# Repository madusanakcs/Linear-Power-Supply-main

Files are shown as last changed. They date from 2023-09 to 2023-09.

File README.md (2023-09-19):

# 10V Linear Power Supply

## Abstract

The objective of this project was to design a 10V Linear power supply with a maximum current rating of 10A. This report presents the design of a voltage regulator from scratch to drive a high-power load (100W) from a 230V input voltage.

## Introduction

Power supplies are used to drive various loads under constant voltage/current conditions. To ensure the reliable operation of a power supply several factors need to be considered including load regulation, line regulation, efficiency, protection mechanism, heat dissipation, etc.

## Design Requirements

- 10V Linear power supply with a maximum current rating of 10A
- Should include circuit protection mechanisms.

## Methodology

### Rectification

The first stage of the DC power supply is rectification which involves converting the input sinusoidal AC voltage to an output voltage with a single polarity. There are many different techniques for implementing the rectification stage in a circuit, however, the most used and simplest method is using a Wheatstone bridge rectifier.

### Smoothing

The second stage is smoothing which reduces the ripple voltage in the output voltage of the rectifier output.

### Regulation

#### Voltage Regulation

The voltage regulation process is a crucial aspect of a linear power supply. To achieve a constant output voltage, a virtual short circuit is utilized in this design. Virtual short circuit refers to 
configuration in a differential amplifier such as op-amp where the inverting and non-invertinginput have almost same voltage. Initially 15v voltage is regulated and 10V is supplied to one of the op-amp terminals,ensuring a constant output voltage of 10V. The op amp is supplied with 15V and 0V to ensure that positive voltage is fed back to the Darlington. In order to further regulate the voltage to the desired level of 12V, a Zener diode is implemented.

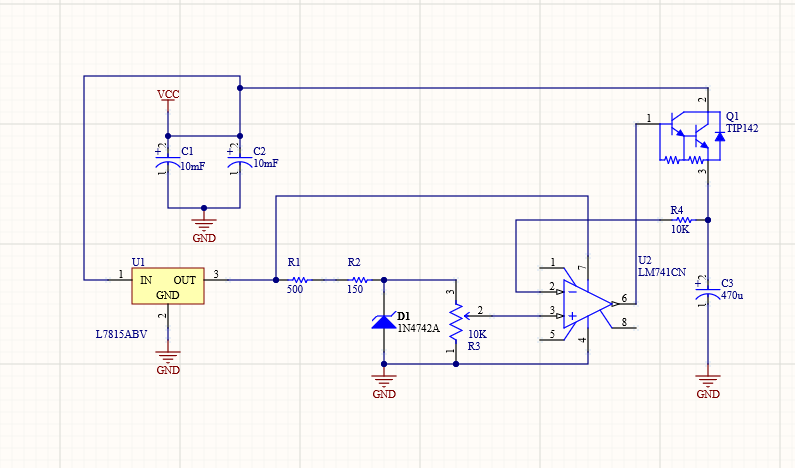
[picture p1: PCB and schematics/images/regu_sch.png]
schematic


#### Current regulation
TIP142 Darlington pair is utilized to control the current. The op-amp provides feedback to the Darlington pair and by using that control the current. Here, the Darlington pair work as a current controlling gate.

### Current Limiting

This power supply is required to limit the maximum current up to 10A. When the current through a circuit exceeds its rated current, it may cause overheating, and component failure. Thus, implementing an overcurrent protection circuit, prevent damage to the device and ensures proper functionality.

The design uses two SPDT relays. An NPN transistor (Q1) is added in series with the coil, along with a 1k resistor (R6) between the supply voltage and the base of the transistor. A flyback diode is added to prevent the occurrence of huge voltage spikes when the relay coil is de-energized. A green LED is used to indicate the absence of over current problem.

To deactivate the coil when an over-current issue occurs, an NPN transistor (Q2) is added to the base of the first transistor. If an error signal is applied to the base of the second transistor (Q2), the base current of the first transistor (Q1) will flow through the second transistor. This causes the coil to deactivate, the LED to turn off, and the contacts to open.

To detect current exceeding 10A a low-value power resistor (Res2) is added between the supply voltage and the first relay contact. This creates a voltage drop proportional to the flowing current, which is amplified using an operational amplifier (op-amp U4A) in differential amplification configuration.

The amplified signal is connected to the non-inverting input of the second op-amp (U4B), whose inverting input is directly connected to the potentiometer, which acts as a variable reference voltage. Since the op-amp functions as a comparator, its output is pulled high when the current sense voltage is higher than the reference voltage. This triggers outputs that are connected to the base of the second transistor (Q2) through a resistor (R5), thus turning off the relay when the current exceeds 10A.

However, once the relay is no longer activated, the flowing current decreases and turns off the output of the comparator, allowing the relay to be activated once again. Since over-current will flow once again when the relay is activated, the comparator triggers once again, and the cycle repeats repeatedly.

To address this, a reset switch (S1) (normally closed push button) with a resistor (R7) is connected between the normally closed contact of the relay K4 and the base of Q2. When current exceeds 10A, the relay turns off, but since normally closed contact is closed, base of Q2 is still pulled to supply voltage even though comparator output is low. As a result, relay remains off until reset button is pushed which interrupts base current of Q2 allowing relay to be activated once again.

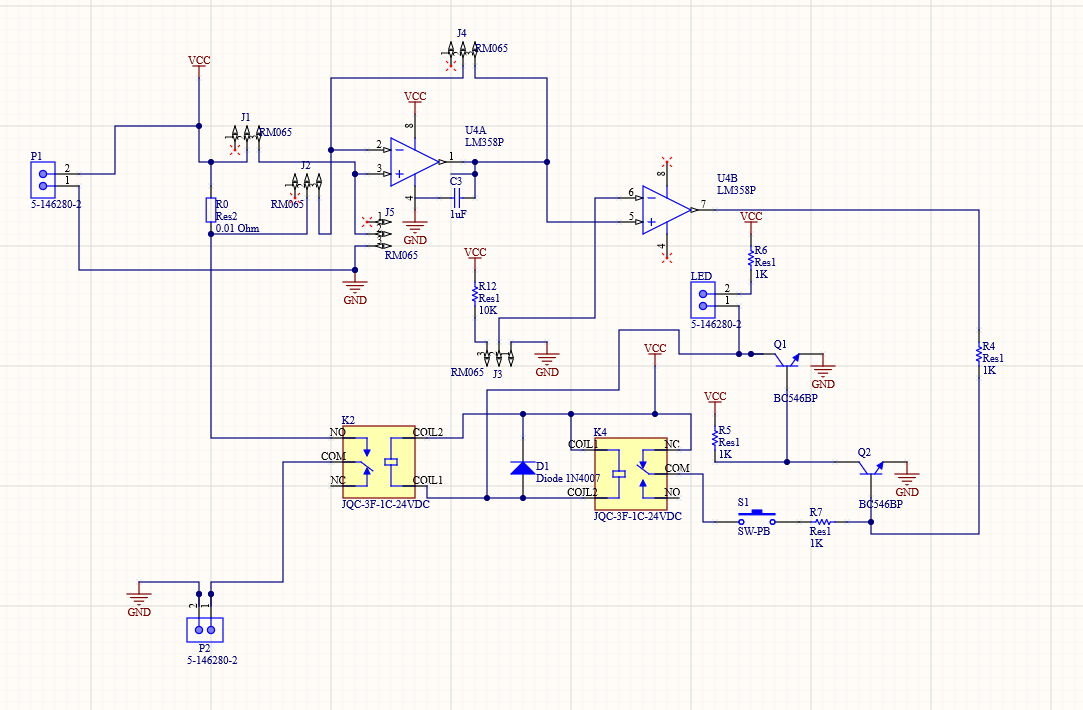
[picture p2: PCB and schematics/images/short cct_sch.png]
schematic


### Protection

#### Short Circuit Protection

The current limiting circuit discussed in section 2.4 is used as short circuit protection. When a short circuit occurs, the current limiting circuit will be activated.

#### Overcurrent Protection

A 12A 250V Fast Blow Glass Fuse (AC fuse) is utilized to implement overcurrent protection. The maximum current allows through the fuse is 12A. 

#### Thermal Protection

Thermal protection is an important consideration in linear power supplies to protect against overheating and potential damage to the circuit. In this design, Heatsinks, Fans and ventilation, and proper PCB design are utilized to implement thermal protection.

## PCB designs
### PCB design of regulation circuit
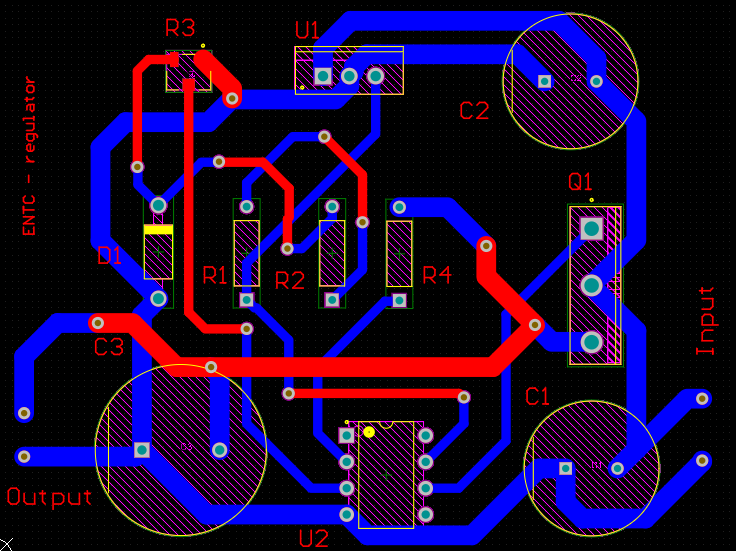
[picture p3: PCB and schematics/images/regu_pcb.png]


### PCB design of current limiting circuit
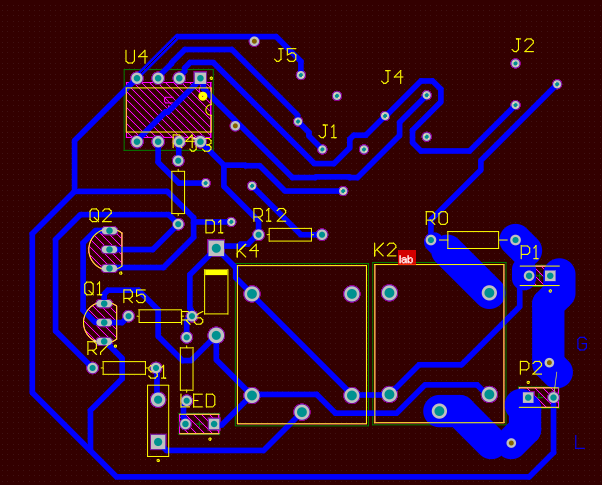
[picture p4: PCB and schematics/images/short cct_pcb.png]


## Conclusion

This project was finalized with two PCB and a 3D-printed enclosure to house the PCB. The power supply was successfully able to drive a high-power load (100W) from a 230V input voltage.

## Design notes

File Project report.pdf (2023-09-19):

Department of Electronic and Telecommunication Engineering

University of Moratuwa

EN2091 – Laboratory Practice and projects

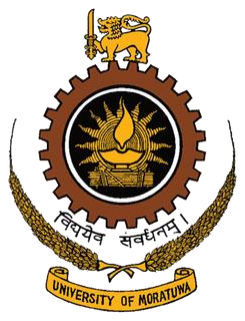
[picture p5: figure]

This is submitted as a partial fulfillment of the module

EN2091: Laboratory Practice and projects

Department of Electronic and Telecommunication University of Moratuwa

February 27, 2023

Name | Index no. | Contribution
AMANA M.A.N. | 200022X | Enclosure design, managing the project report, Assembling the enclosure
GAMIDU A.G.D. | 200179H | Designing the over-current protection circuit, Testing the circuit, Assembling the enclosure
MADUSAN A.K.C.S. | 200366E | PCB designing, Assembling the enclosure
RATHNASEKARA T.S. | 200529H | Designing the power supply circuit designing, PCB Designing, Creating the datasheet of the product

## Contents

Abstract | 3
Section 1 – Introduction – Our Design | 3
Section 2 –Methodology | 3
I. | Section 2.1 – Rectification | 3
II. | Section 2.2 – Smoothing | 4
III. | Section 2.3 - Regulation | 5
IV. | Section 2.4 – Current Limiting | 5
V. | Section 2.5 – Circuit Protection | 6
i. | Section 2.5.1 – Overload Protection | 6
ii. | Section 2.5.2 – Short Circuit Protection | 6
iii. | Section 2.5.3 – Thermal Protection | 6
Section 3 – Results | 7
PCB Design | 7
Enclosure design | 7
Conclusion | 8
References | 8
Appendices | 9
I. | Appendix A – Our Product | 9
II. | Appendix B – PCB Design | 9
III. | Appendix C – Enclosure Design | 9
IV. | Appendix D – Data Sheet of the Linear Power Supply | 9

### Abstract

The objective of the project was to design a 10 V Linear power supply with a maximum current rating of 10 A. This report presents the design of a voltage regulator from scratch to drive a high-power load (100 W) from 230 V input voltage. A step-down transformer was provided to reduce the 230V input line voltage to a 15V (rms) AC voltage. The transformer output voltage is rectified using the BR3510 bridge rectifier and smoothed using two 10mF 50V capacitors in parallel configuration. LM7815 voltage regulator, 12V Zener diode, and LM741CN op amp in virtual circuit configuration are used to implement voltage regulation. TIP142 Darlington pair is used in the current regulation stage. Furthermore, our design consists current limiting circuit and a 12A glass fuse is used to overload protection. 12V DC fan and ventilation, heat sinks are used for thermal protection. Our project was finalized with two PCB and a 3Dprinted enclosure to house the PCB.

### Section 1 - Introduction

Power supplies are used to drive various loads under constant voltage/current conditions. To ensure the reliable operation of a power supply several factors need to be considered including load regulation, line regulation, efficiency, protection mechanism, heat dissipation, etc.

The assigned task is to design a voltage regulator from scratch to drive a high-power load (100 W) from 230 V input voltage.

The power supply to be made should meet the following design requirements.

- 10 V Linear power supply with a maximum current rating of 10 A
- | Should | include | circuit | protection
mechanisms.
- Power supply efficiency should be considered when developing the circuit.

The design process includes,

1. Rectification: convert AC output from the transformer to DC voltage
2. Smoothing: reduce the ripple voltage in the output voltage of the rectifier output.
3. Regulation: maintaining the constant output voltage.
4. Protection

### Section 2 - Methodology

Section 2.1 - Rectification

The first stage of the DC power supply is rectification which involves converting the input sinusoidal AC voltage to an output voltage with a single polarity. There are many different techniques for implementing the rectification stage in a circuit, however, the most used and simplest method is using a Wheatstone bridge rectifier.

Wheatstone bridge rectifier consists of four diodes. Each diode is arranged to conduct only during one half-cycle of the input AC waveform, allowing the output to be a positive voltage.

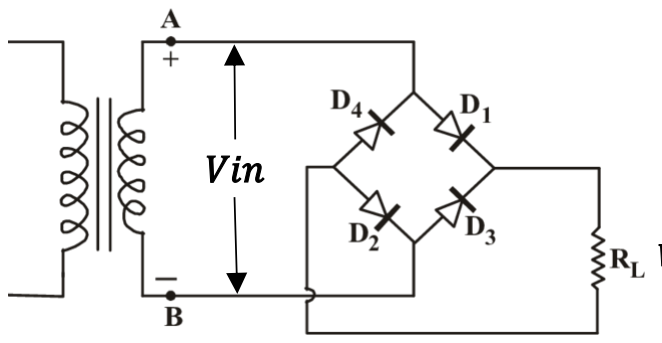
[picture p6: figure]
Vin

By analyzing the circuit, we can derive a set of equations that describe the behavior of the rectifier in terms of its output voltage (Vout) and the voltage across a reversed-biased diode (Vrev), as they relate to the input voltage (Vin) and the nominal voltage drop across a forward-biased diode (Vd). It is important to note that the equations are only applicable when the output current is forward-biased, that is, when |Vin| ≥ 2Vd.

Vout

Vout = |Vin| − 2 Vd | Eq. 1
Vrev = |Vin| − Vd | Eq. 2

The transformer provided for this project is a step-down transformer with a voltage ratio of 230:15. Therefore, when connected to the household power supply, the transformer will supply a 15V rms input voltage to the rectifier. The peak voltage of the input waveform is calculated as √2 × 15 = 21.21V. Assuming a nominal voltage drop of 0.7V for Vd, the peak voltage of the rectified output waveform can be calculated using Eq. 1 as

Vout = 21.21 − 2 × 0.7 = 19.81V

The waveforms of the AC input and the rectified DC output of the rectifier bridge are illustrated in Figure 3.

The Peak Inverse Voltage (PIV rating) is defined as the maximum voltage that can be applied across its reverse-biased diodes. By applying Eq. 2 at the peak of the rectifier input waveform, the PIV value can be computed as

PIV = 21.21 − 0.7 = 20.51V

The Wheatstone Bridge Rectifier, as illustrated in Figure 2, was used in our design and we implemented it using a commercially available bridge rectifier chip KBPC3510. This chip can support a maximum average output current of 35A, which is sufficient for a 10A DC power supply. Moreover, the maximum peak reverse voltage of the chip is 1000V, which is much higher than the PIV value suggested by our calculations.

Section 2.2 - Smoothing

Smoothing is the process of reducing variation or ripples of rectifier output voltage. This is typically done by adding a capacitor parallel to the rectifier output. When rectified AC output is applied across the capacitor, the capacitor charges during the positive half and discharges during the negative half. The resulting voltage variation due to the discharge of a capacitor over a resistive load can be expressed by the following equation, which is referred to as Eq.3 in the previous context:

VR(t) = Vp e

−T
RC

dVR(t)
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
In this equation, VR(t) represents the output voltage of the smoothing circuit at a given time t. VP represents the peak voltage of the rectified AC voltage (maximum voltage that the capacitor can charge up to). RC represents the time constant of the RC circuit.

In order to achieve a better smoothing effect, the

capacitor must discharge slowly.

dVR(t)
dt

need to

be low value. Although this can be achieved by increasing the value of the RC time constant, since R is beyond the control of the power supply, the only controllable factor in the design is the capacitance of the smoothing capacitor C.

However, Increasing the capacitance increases the surge current drawn to charge the capacitor which may cause to damage the rectifier diodes. Thus, capacitors need to be selected considering the surge current limit and desired amount of smoothing.

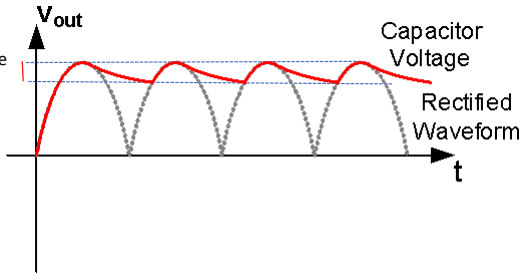
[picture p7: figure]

Since 10V steady voltage is expected,

Vripple =19.81 - 10 = 9.81V

Since 50Hz household voltage is used in initial stage, the rectified voltage frequency is 100Hz. Thus, T is 1/100.

Vripple

VR(t) = Vp e

−T
RC

By approximating,

VR(t) = Vp(1 −

T
RC

)

Vripple = 9.81 = Vp

T
RC

= 19.81×

100
RC

C = 19.81
981×R

Since the minimum R is about 1Ω as satisfying the maximum current 10A,

C ≈ 20.194 mF

Based on obtained results, 20mF capacitor was selected as smoothing capacitor. This is approached by using two 10mF capacitors in parallel configuration.

Section 2.3 - Regulation

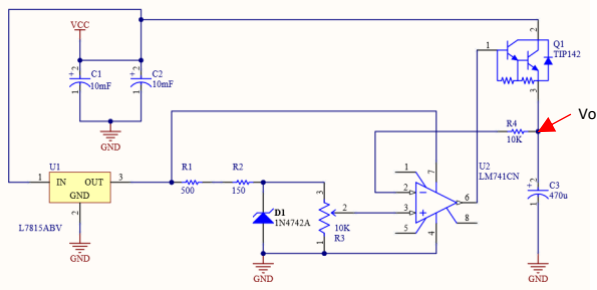
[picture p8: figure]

Voltage regulation

The voltage regulation process is a crucial aspect of a linear power supply. To achieve a constant output voltage, a virtual short circuit is utilized in this design. Virtual short circuit refers to a configuration in a differential amplifier such as op-amp where the inverting and non-inverting input have almost same voltage. Initially 15v voltage is regulated and 10V is supplied to one of the op-amp terminals, ensuring a constant output voltage of 10V. The op amp is supplied with 15V and 0V to ensure that positive voltage is fed back to the Darlington. In order to further regulate the voltage to the desired level of 12V, a Zener diode is implemented.

Initially, an LM7812 was used, but it produced unacceptable ripple. Therefore, an LM7815 and a

12V Zener diode (IN4742) have been substituted. Finally, to ensure safety, a resistor R1 is incorporated into the circuit.

Current regulation

TIP142 Darlington pair is utilized to control the current. The op-amp provides feedback to the Darlington pair and by using that control the current. Here, the Darlington pair work as a current controlling gate.

Initially, a MOSFET was utilized for current control, but it resulted in a high-frequency oscillation at higher current levels. Therefore, the MOSFET has been substituted with a Darlington pair for improved performance.

Section 2.4 - Current limiting

This power supply is required to limit the maximum current up to 10A. When the current through a circuit exceeds its rated current, it may cause overheating, and component failure. Thus, implementing an over-current protection circuit, prevent damage to the device and ensures proper functionality.

There are many techniques to implement current limiting circuit. The use of a relay is a common practice. In such circuits, changeover contacts are utilized to connect the supply voltage when the current is lower than the rated current and to open the contact when the current exceeded the rated current. Two spdt relays are utilized in this design. Since normally open contact points are used, current must be allowed to flow through the coil so that the contacts remain closed. To address this, an NPN transistor (Q1) is added in series with the coil, along with a 1k resistor (R6) between the supply voltage and the base of the transistor. When voltage is applied to the circuit, current flows through the base-emitter path of the transistor and causes it to operate in the saturated region. As a result, the coil of both relays are energized, and the contact is closed. A flyback diode is added to prevent the occurrence of huge voltage spikes when the relay coil is deenergized. A green LED is used to indicate the absence of over current problem.

Vout

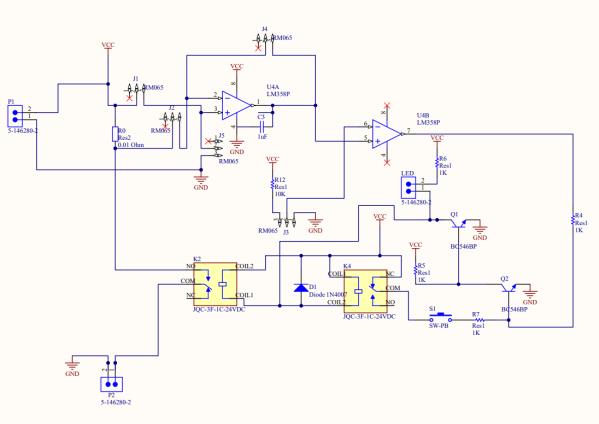
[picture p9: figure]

To deactivate the coil when an over-current issue occurs, an NPN transistor (Q2) is added to the base of the first transistor. If an error signal is applied to the base of the second transistor (Q2), the base current of the first transistor (Q1) will flow through the second transistor. This causes the coil to deactivate, the LED to turn off, and the contacts to open.

To detect current exceeding 10A a low-value power resistor (Res2) is added between the supply voltage and the first relay contact. 0.1-ohm 10W resistor is intent to use for this design. Since it’s not available in market thick copper wire is used. This creates a voltage drop proportional to the flowing current, which is amplified using an operational amplifier (op-amp U4A) in differential amplification configuration. The amplified signal is connected to the non-inverting input of the second op-amp (U4B), whose inverting input is directly connected to the potentiometer, which acts as a variable reference voltage. Since the op-amp functions as a comparator, its output is pulled high when the current sense voltage is higher than the reference voltage. This triggers outputs that are connected to the base of the second transistor (Q2) through a resistor (R5), thus turning off the relay when the current exceeds 10A.

However, once the relay is no longer activated, the flowing current decreases and turns off the output of the comparator, allowing the relay to be activated once again. Since over-current will flow once again when the relay is activated, the comparator triggers once again, and the cycle repeats repeatedly.

To address this, a reset switch (S1) (normally closed push button) with a resistor (R7) is connected between the normally closed contact of the relay K4 and the base of the Q2. When current exceeds 10A, the relay turns off, but since the normally closed contact is closed, the base of the Q2 is still pulled to the supply voltage, even though the comparator output is low. As a result, the relay remains off until the reset button is pushed, which interrupts the base current of the Q2, allowing the relay to be activated once again.

Section 2.5 - Protection

Section 2.5.1 - Short circuit protection

The current limiting circuit discussed in section 2.4 is used as short circuit protection. When a short circuit occurred, the current limiting circuit will be activated.

Section 2.5.2 - Overcurrent protection

12A 250V Fast Blow Glass Fuse (AC fuse) is utilized to implement overcurrent protection. The maximum current allows through the fuse is 12A. Fuse is connected to the 15V transformer output, which burns out when input current exceeds 12A. However, the circuit may experience a higher current for a short amount of time until the fuse wire melts. This current will go through the KBPC3510 bridge rectifier, capacitors, and TIP142 Darlington pair. Thus these components need to tolerate such high currents.

Section 2.5.3 - Thermal Protection

Thermal protection is an important consideration in linear power supplies to protect against overheating and potential damage to the circuit. In this design, Heatsinks, Fans and ventilation, and proper PCB design are utilized to implement thermal protection.

12V DC fan is used to ventilate the power supply unit. LM7812V is used to provide 12V DC power supply to the fan. Enclosure design includes air vents for the heated air to flow outside.

To provide effective thermal conductance, heat sink is utilized. In this design, heatsinks are utilized for the TIP142 Darlington pair the KBPC3510 bridge rectifier since a higher current of 10A will pass through these components during extreme conditions. Heatsinks are used for LM7812 and LM7815 as well due to the fact that these components generate a significant amount of heat. Also, we used thermal paste and thermal conducting current insulated mica sheet to make the contact between the heatsinks and the components.

Furthermore, heatsinks are mounted using spacer screws to avoid any contact with the PCB. In the PCB, copper traces designed to carry the load current were made wider and shorter to reduce path resistance, which ensures that PCB does not
overheat | during | extreme | conditions.
Furthermore, proper wire connectors with necessary current ratings were used for the devices connected to the external heat sinks to avoid overheating and other failures.

### Section 3 - Results

After the designing stage, the circuit was tested using multisim simulation software. In the next stage, the prototype was built using breadboards and tested. Since breadboard implementation met the requirements, Finally prototype was built using PCB.

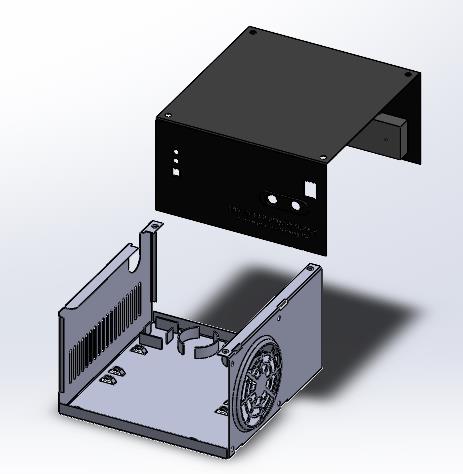
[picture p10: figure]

Checking the Circuit

Checking the Circuit is important to identify any problems or faults such as loose connections, damaged components, short circuits, etc. Here, we checked for any error in the circuit, including the component soldering, electrical continuity of the paths, wire connections, and component pin configurations.

Verifying the functionality

First, we checked functionality in no load configuration and the 10K potentiometer is calibrated to obtain 10V steady voltage. Short circuit protection circuit is verified by creating short circuit configuration purposely. At the next step measurements are obtained for the datasheet by varying the load resistor value.

PCB design

Since 10A current draw through the circuit in extreme condition, PCB can get heated up easily. To avoid heating of PCB, several techniques are used. High-power components such as rectifier two mF capacitors and the Darlington pair are placed outside the PCB and fixed to the enclosure. copper traces designed to carry the load current were made wider and shorter to reduce path resistance, which ensures that PCB does not overheat during extreme conditions. Furthermore, power wires are used for high power paths.

Enclosure

Since metal providing electromagnetic shielding, high heat dissipation and the degree of wire resistance, metal enclosure is used.

Enclosure Design

The enclosure design for the Linear Power Supply was designed using SOLIDWORKS 2020 software.

Enclosure design contain of two parts. Those parts are assembled using four screws.

Ventilation holes are used to allow for airflow and heat dissipation.

Future works

We plan to replace the copper wire currently used in the current limiting circuit with a reliable resistor. Additionally, we wish to improve the efficiency and to employ high-quality PCBs to develop a high-quality product.

Conclusion

This report has presented the designing process of 10V linear power supply with 10A maximum current. Both the simulation and the physical
implementation | confirmed | its | required
performance with good voltage regulation and lo
implementation | confirmed | its | required
performance with good voltage regulation and low ripple.

References

KBPC3510datasheet

https://pdf1.alldatasheet.com/datasheetpdf/view/814963/DGNJDZ/KBPC3510.html (https://pdf1.alldatasheet.com/datasheet-pdf/view/814963/DGNJDZ/KBPC3510.html)

LM7815 datasheet

https://pdf1.alldatasheet.com/datasheetpdf/view/83945/ETC/LM7815.html (https://pdf1.alldatasheet.com/datasheet-pdf/view/83945/ETC/LM7815.html)

LM741N datasheet

https://pdf1.alldatasheet.com/datasheetpdf/view/198081/SEOUL/LM741.html (https://pdf1.alldatasheet.com/datasheet-pdf/view/198081/SEOUL/LM741.html)

LM358P datasheet

https://pdf1.alldatasheet.com/datasheetpdf/view/3067/MOTOROLA/LM358.html (https://pdf1.alldatasheet.com/datasheet-pdf/view/3067/MOTOROLA/LM358.html)

BC546 datasheet

https://pdf1.alldatasheet.com/datasheetpdf/view/596620/FAIRCHILD/BC546.html (https://pdf1.alldatasheet.com/datasheet-pdf/view/596620/FAIRCHILD/BC546.html)

TIP142 datasheet

https://pdf1.alldatasheet.com/datasheetpdf/view/2772/MOSPEC/TIP142.html (https://pdf1.alldatasheet.com/datasheet-pdf/view/2772/MOSPEC/TIP142.html)

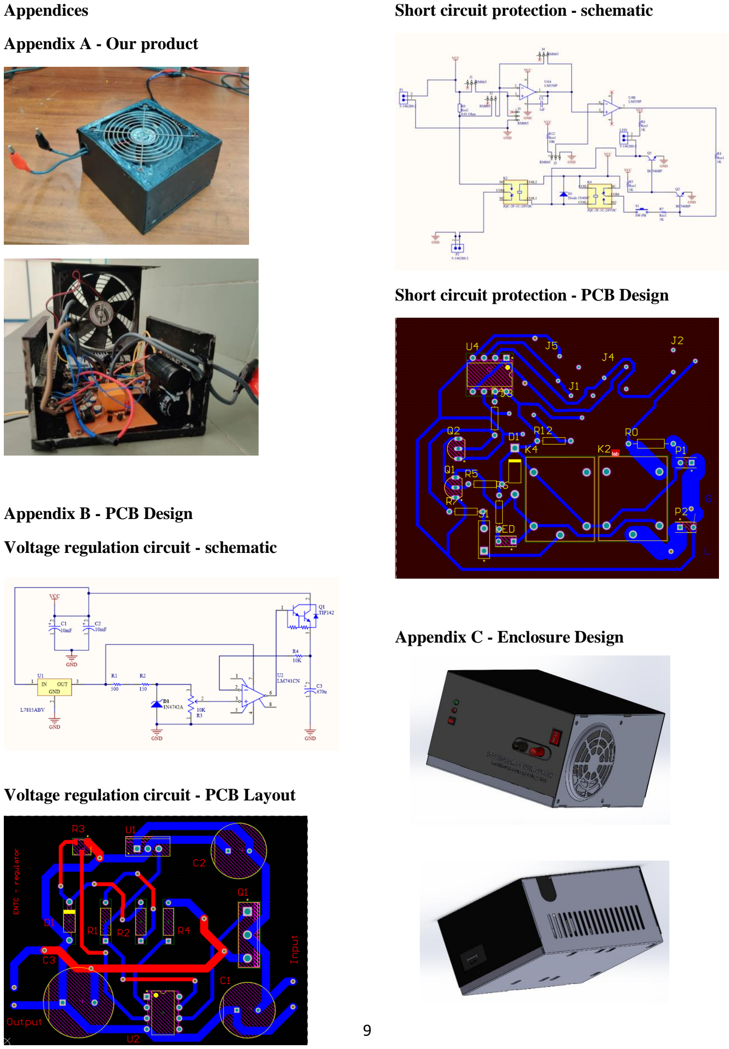
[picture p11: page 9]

Appendices

Appendix A - Our product

Appendix B - PCB Design

Voltage regulation circuit - schematic

Voltage regulation circuit - PCB Layout

Short circuit protection - schematic

Short circuit protection - PCB Design

Appendix C - Enclosure Design

Appendix D - Data sheet of Linear Power Supply

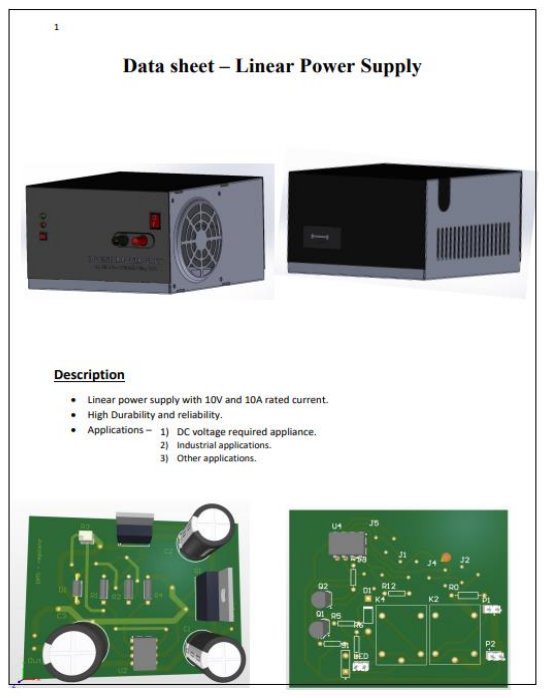
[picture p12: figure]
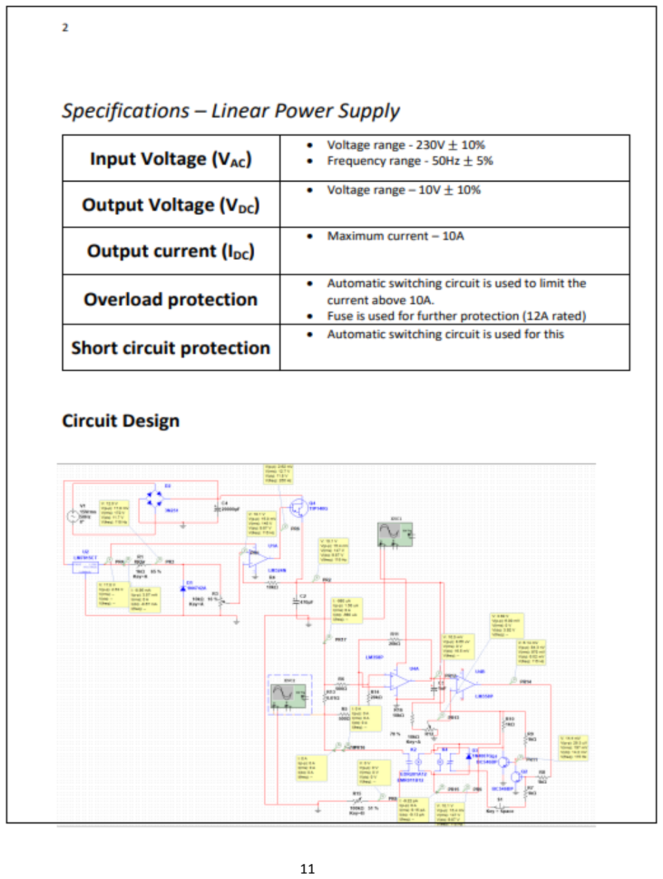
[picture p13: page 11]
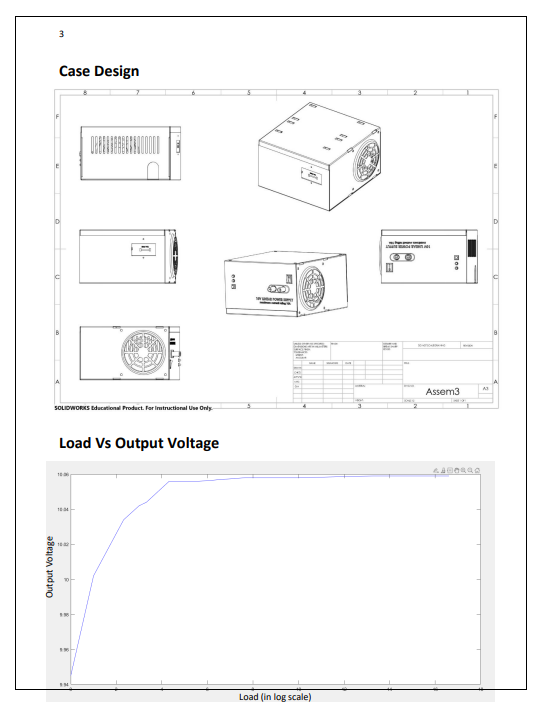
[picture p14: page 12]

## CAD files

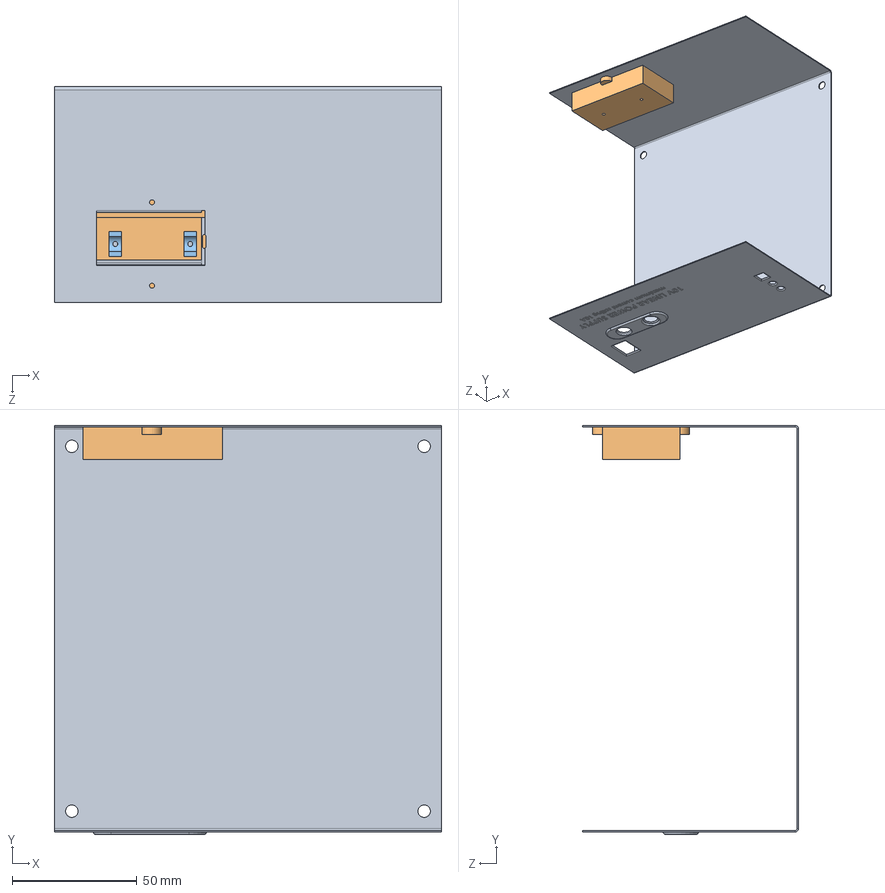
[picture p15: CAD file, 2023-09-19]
Solidworks design files/cahsis2 asssembed.SLDASM
155.0 x 163.7 x 86.4 mm
chasis2
fuse box
ring x 2

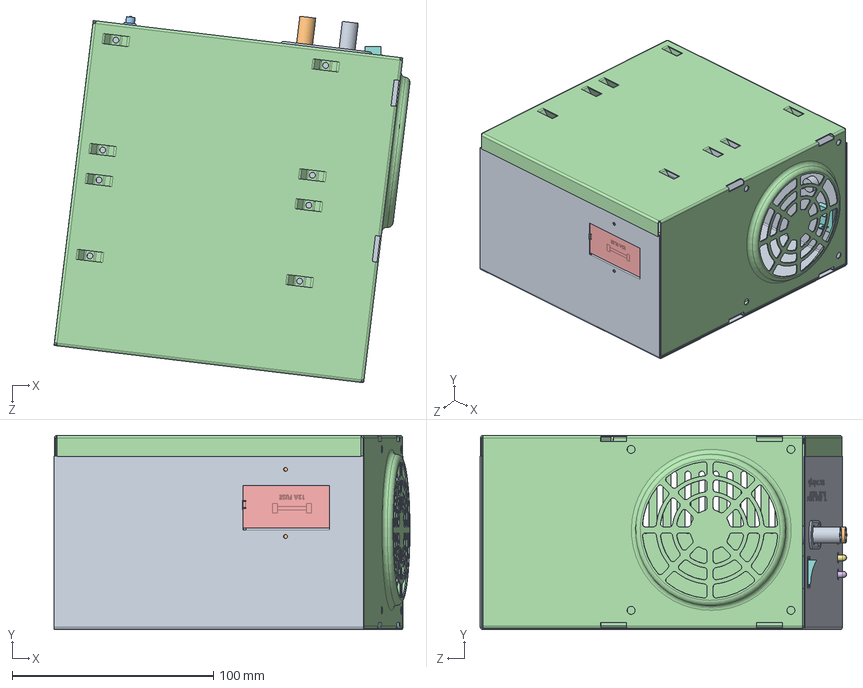
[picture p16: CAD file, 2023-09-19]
Solidworks design files/Assem3.SLDASM
176.9 x 96.6 x 182.2 mm
chasis2
fuse box
ring x 2
chasis1
lid
green LED
red LED
switch
probe part red
probe part black
push button

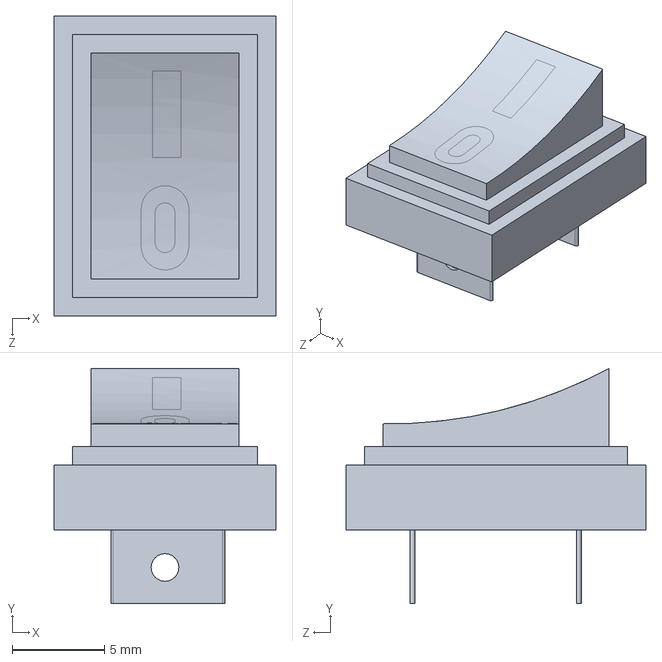
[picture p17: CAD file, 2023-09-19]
Solidworks design files/switch.SLDPRT
12.0 x 12.7 x 16.2 mm

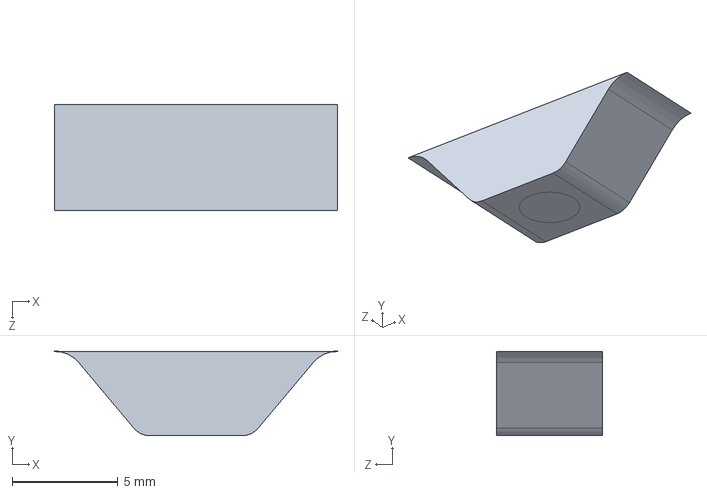
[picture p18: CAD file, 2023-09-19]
Solidworks design files/Part1.SLDPRT
13.4 x 4.00 x 5.00 mm

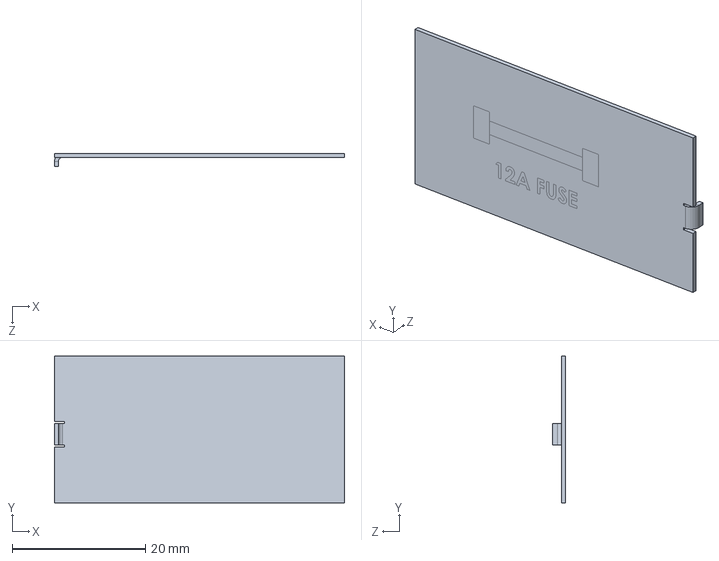
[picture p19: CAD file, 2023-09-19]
Solidworks design files/lid.SLDPRT
43.5 x 22.0 x 2.00 mm

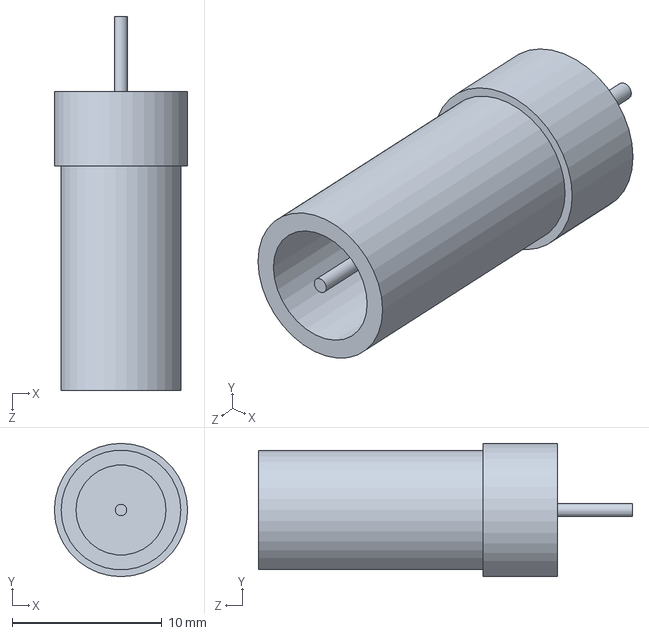
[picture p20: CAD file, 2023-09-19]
Solidworks design files/probe part red.SLDPRT
8.91 x 8.91 x 25.0 mm

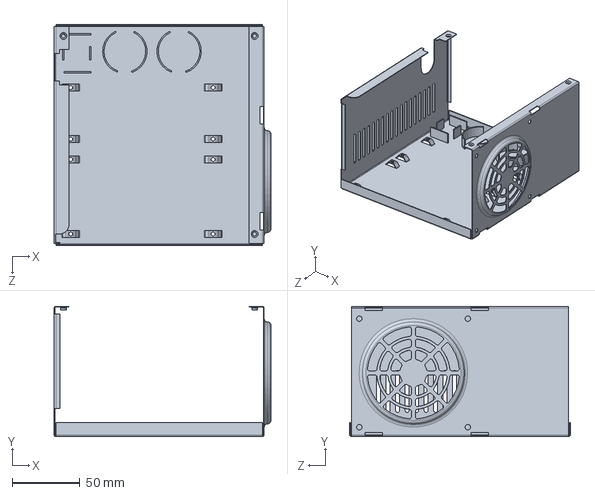
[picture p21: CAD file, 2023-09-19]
Solidworks design files/chasis1.SLDPRT
160.0 x 96.0 x 162.7 mm

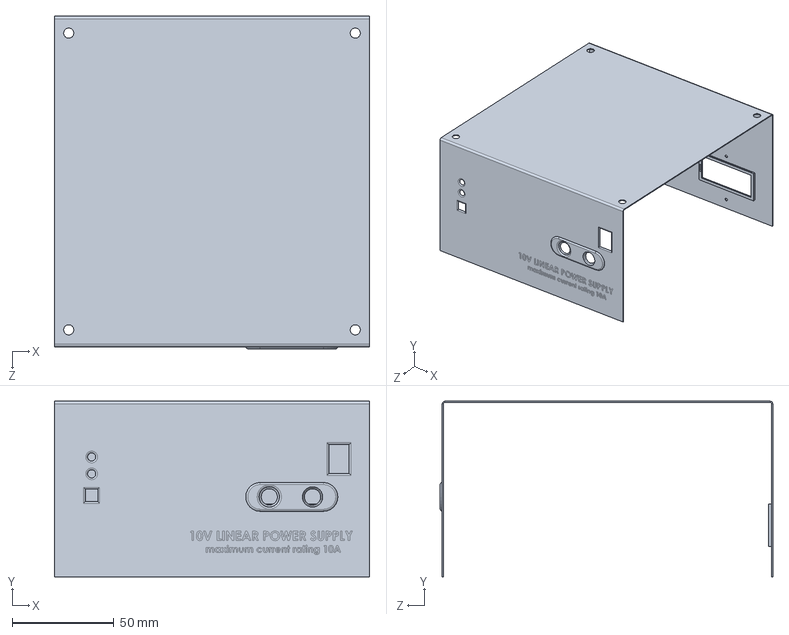
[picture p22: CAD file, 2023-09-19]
Solidworks design files/chasis2.SLDPRT
155.0 x 86.4 x 163.7 mm

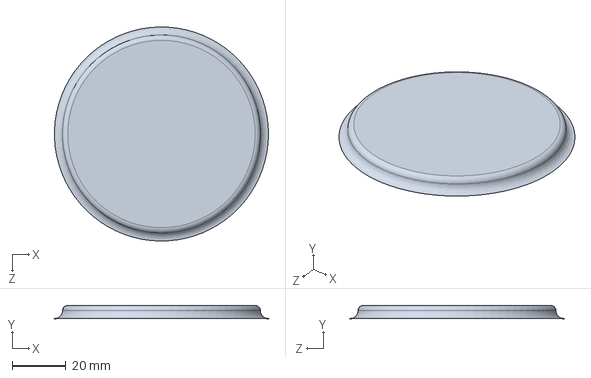
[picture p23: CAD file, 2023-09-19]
Solidworks design files/Part2.SLDPRT
80.0 x 5.00 x 80.0 mm

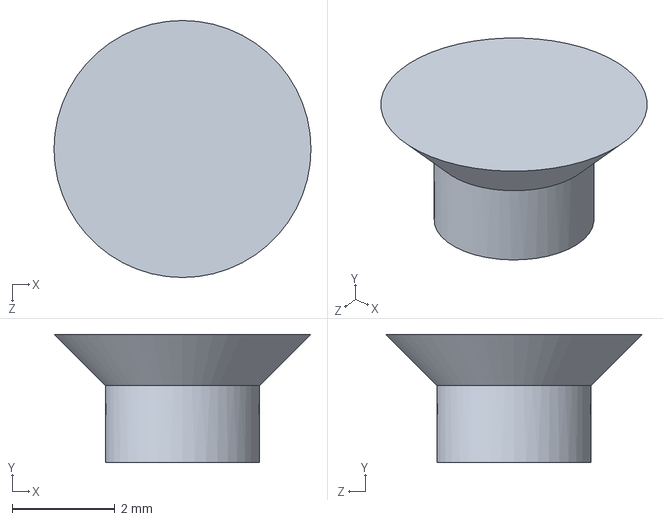
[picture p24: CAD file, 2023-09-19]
Solidworks design files/Part3.SLDPRT
5.00 x 2.50 x 5.00 mm

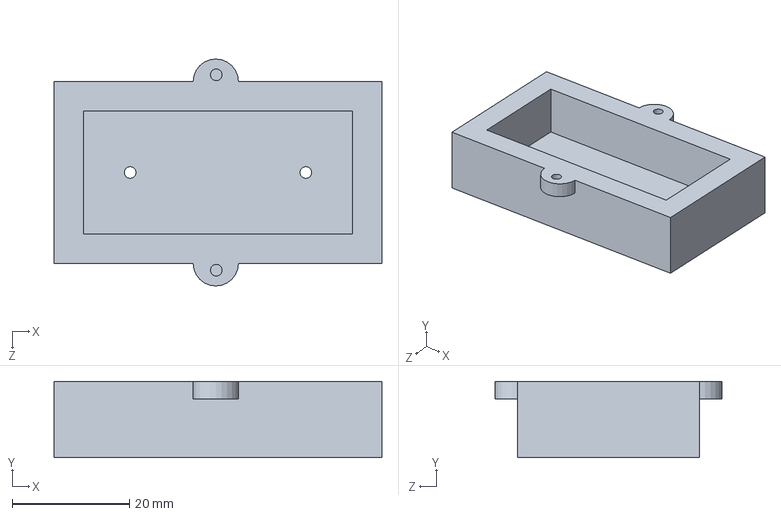
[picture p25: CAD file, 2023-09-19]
Solidworks design files/fuse box.SLDPRT
56.0 x 13.0 x 38.8 mm

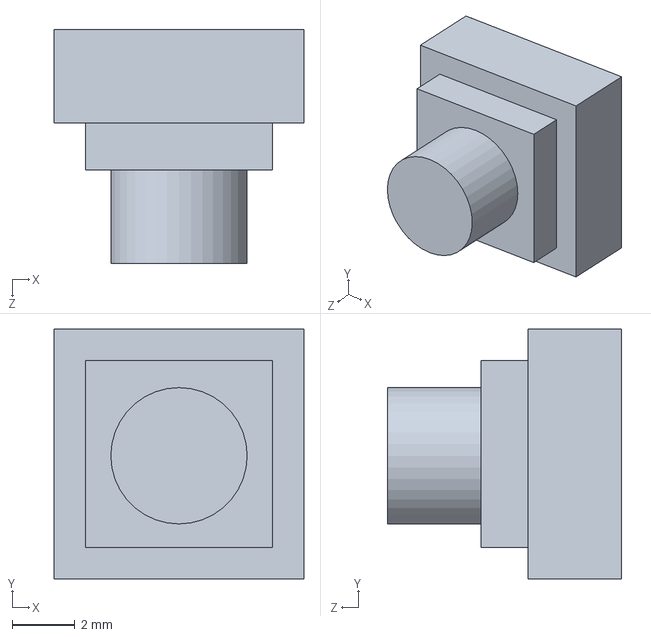
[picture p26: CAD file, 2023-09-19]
Solidworks design files/push button.SLDPRT
8.00 x 8.00 x 7.50 mm

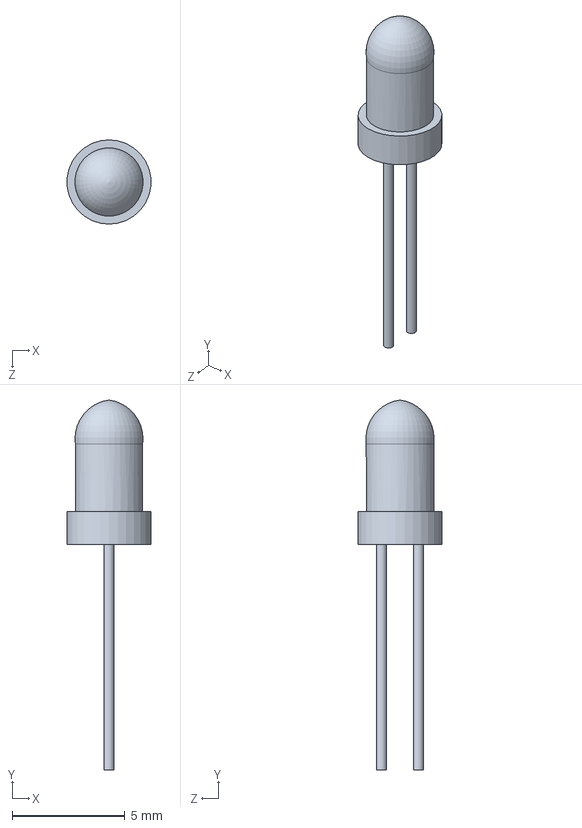
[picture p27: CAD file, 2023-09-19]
Solidworks design files/green LED.SLDPRT
3.72 x 16.4 x 3.74 mm

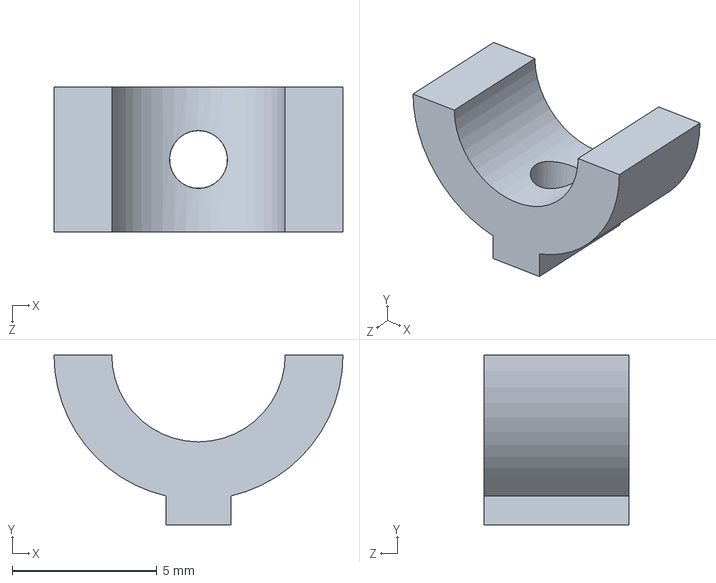
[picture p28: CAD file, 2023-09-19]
Solidworks design files/ring.SLDPRT
10.00 x 5.87 x 5.00 mm

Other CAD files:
Solidworks design files/probe part black.SLDPRT
Solidworks design files/red LED.SLDPRT
Solidworks design files/Assem3.SLDDRW

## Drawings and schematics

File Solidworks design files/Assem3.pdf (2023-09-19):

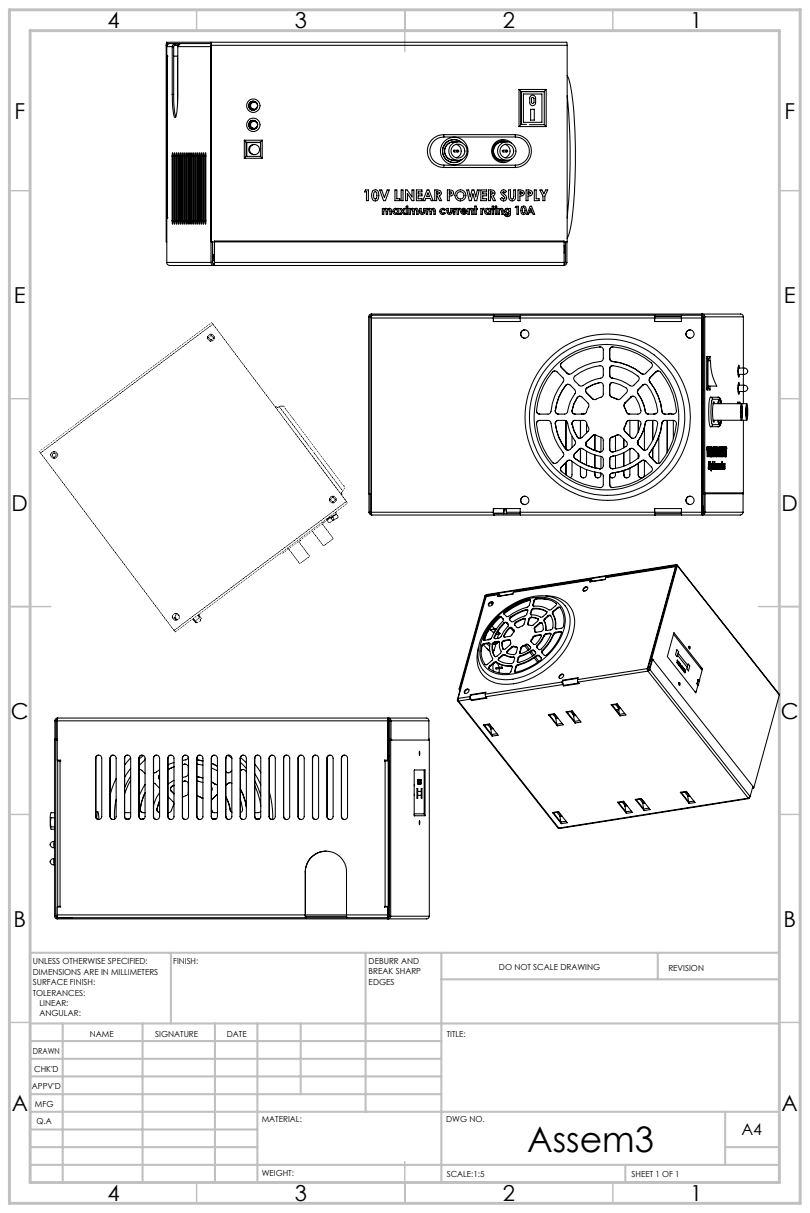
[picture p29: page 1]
FINISH:; DEBURR AND; BREAK SHARP; DO NOT SCALE DRAWING; REVISION; SCALE:1:5; SHEET 1 OF 1

UNLESS OTHERWISE SPECIFIED:
DIMENSIONS ARE IN MILLIMETERS
SURFACE FINISH:
TOLERANCES:
LINEAR:
ANGULAR:

NAME | SIGNATURE | DATE | | | | TITLE:

DRAWN
CHK'D
APPV'D
MFG
Q.A | | | | MATERIAL: | DWG NO. Assem3 | A4
